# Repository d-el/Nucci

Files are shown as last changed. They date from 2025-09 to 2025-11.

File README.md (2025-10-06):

# Nucci -- NUClear Counter Interface

## Overview

- IPS 160x128 pixel front panel display
- 10/100BASE-T Ethernet
- Modbus TCP for remote programming
- Web interface for monitoring

## Specifications and features

Current consumption from a 3.7V battery is 0.142A (3.408Ah per twenty-four hours) with the backlight on, 0.114A (2.736Ah per twenty-four hours) with the backlight off.

The detector tube voltage is set from the menu in the range of 100-450V.

## Hardware

Assembly:  
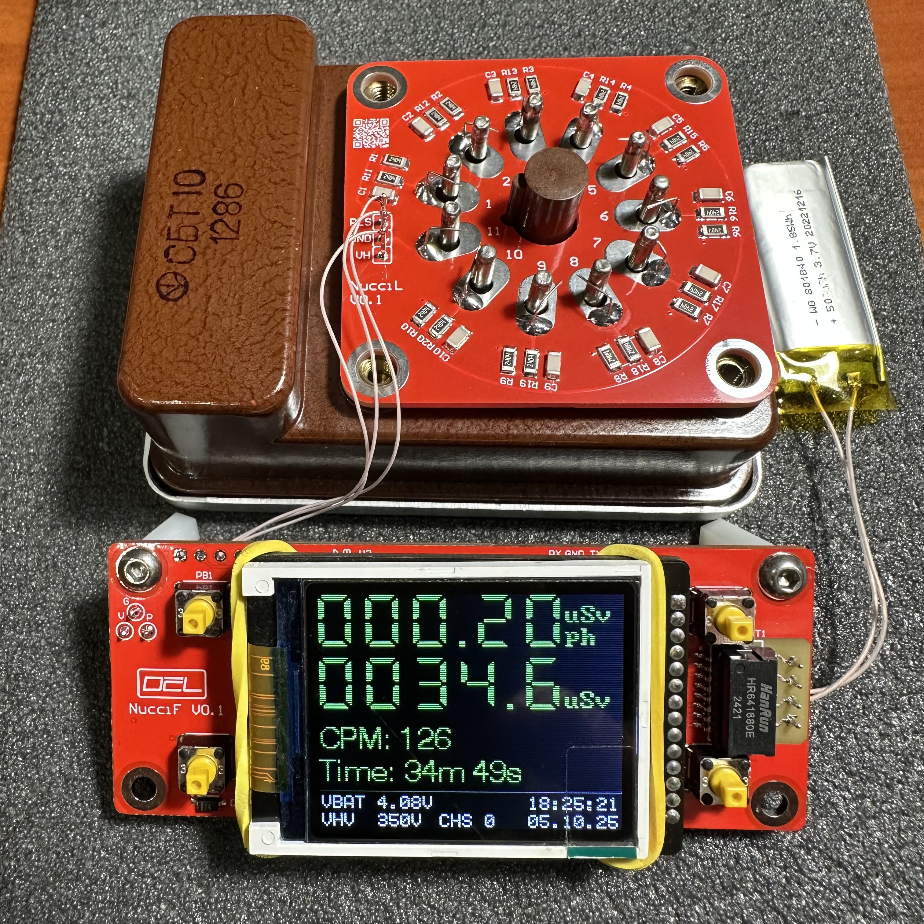
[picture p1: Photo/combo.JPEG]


PCB top:  
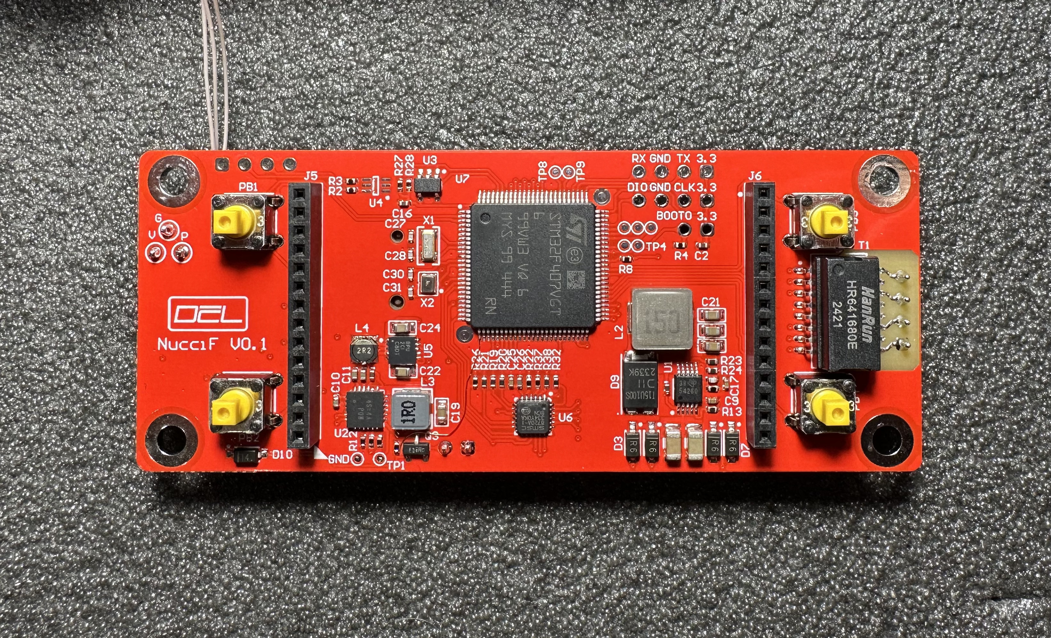
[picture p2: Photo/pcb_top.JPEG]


PCB bottom:  
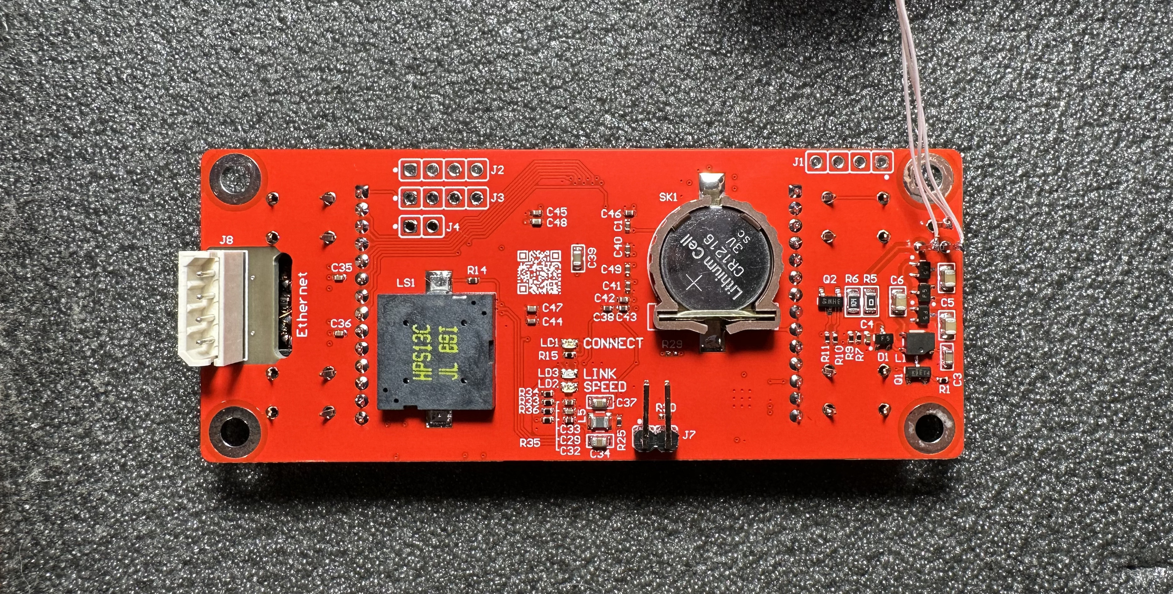
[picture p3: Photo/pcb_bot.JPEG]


SBT10 connector:  
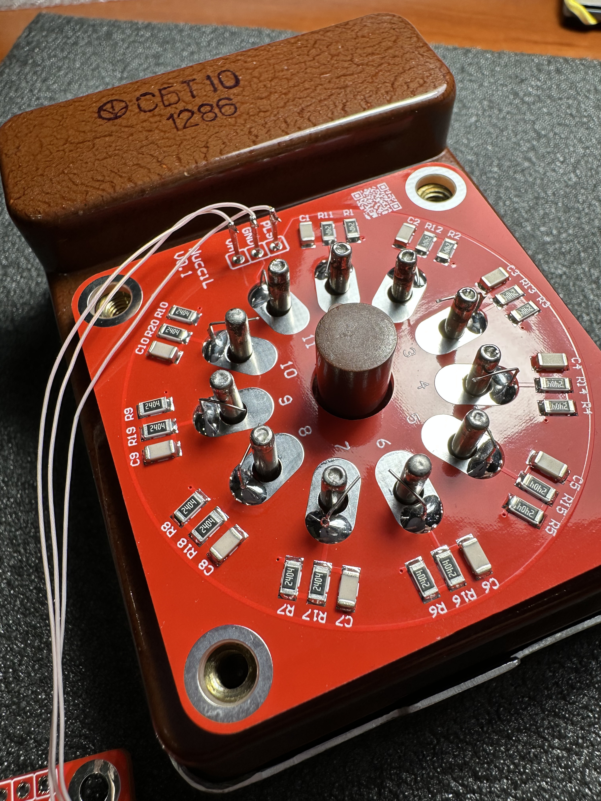
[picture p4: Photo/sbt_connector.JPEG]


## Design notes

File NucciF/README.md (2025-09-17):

# Nucci

### Overview
This repository include the source code of the counter on Geiger tube.  
MCU: STM32F407VG.

### Requirements
toolchain arm-none-eabi 14.2.1 or higher  
gcc / g++ 13.3.0 or higher  
cmake 3.14 or higher  
libjsoncpp-dev  

### Build project
>mkdir build  
>cd build  
>cmake .. -G "Unix Makefiles" -DCMAKE_TOOLCHAIN_FILE=../toolchain.cmake -DCMAKE_BUILD_TYPE=Release  
>make -j8  

#### Start debug server
>./scripts/gdb-serv.sh openocd-jlink

#### Start debug client
>./scripts/gdb-client.sh

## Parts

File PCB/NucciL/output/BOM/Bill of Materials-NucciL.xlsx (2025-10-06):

Designator | Comment | Footprint | Part Number | Part Description | Quantity
C1, C2, C3, C4, C5, C6, C7, C8, C9, C10 | 10p | CAPC3216X70N | CC1206_10PF_500V_5%_NP0 | SMD Multilayer Chip Ceramic Capacitor | 10
R1, R2, R3, R4, R5, R6, R7, R8, R9, R10, R11, R12, R13, R14, R15, R16, R17, R18, R19, R20 | 2M4 | RESC3216X65N | R1206_2M4_1%_0.25W_100PPM | General Purpose Thick Film Chip Resistor | 20
W1 | Test Point | COMATEL_385.0358.1.03.400 | COMATEL_385.0358.1.03.400 | 3 Contacts Straight Strip Header Pitch 2.54mm L=6.3mm ''Mini-Wire-Wrap'' | 1

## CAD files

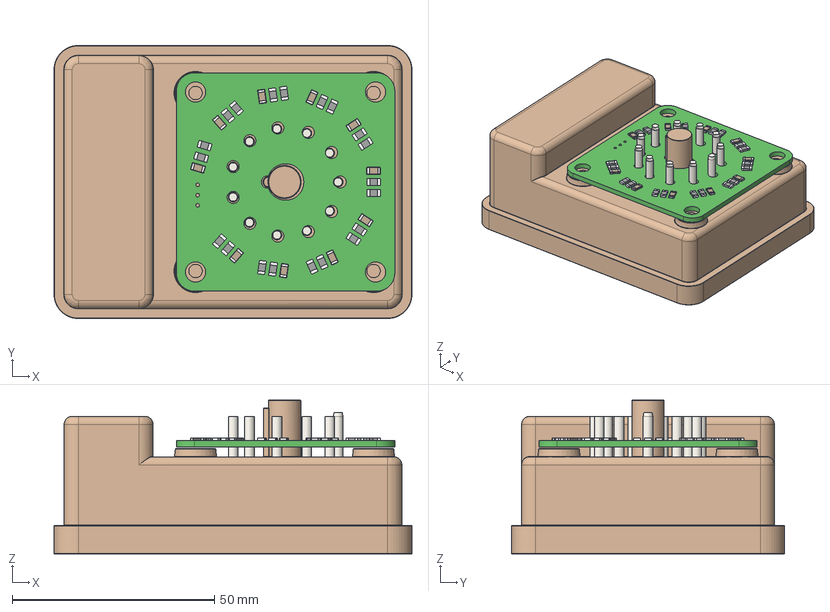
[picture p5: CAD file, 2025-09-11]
PCB/NucciL/NucciL.step
88.5 x 67.5 x 38.0 mm
RESC3216X65N x 20
CAPC3216X70N x 10
SBT-10A_Sonde

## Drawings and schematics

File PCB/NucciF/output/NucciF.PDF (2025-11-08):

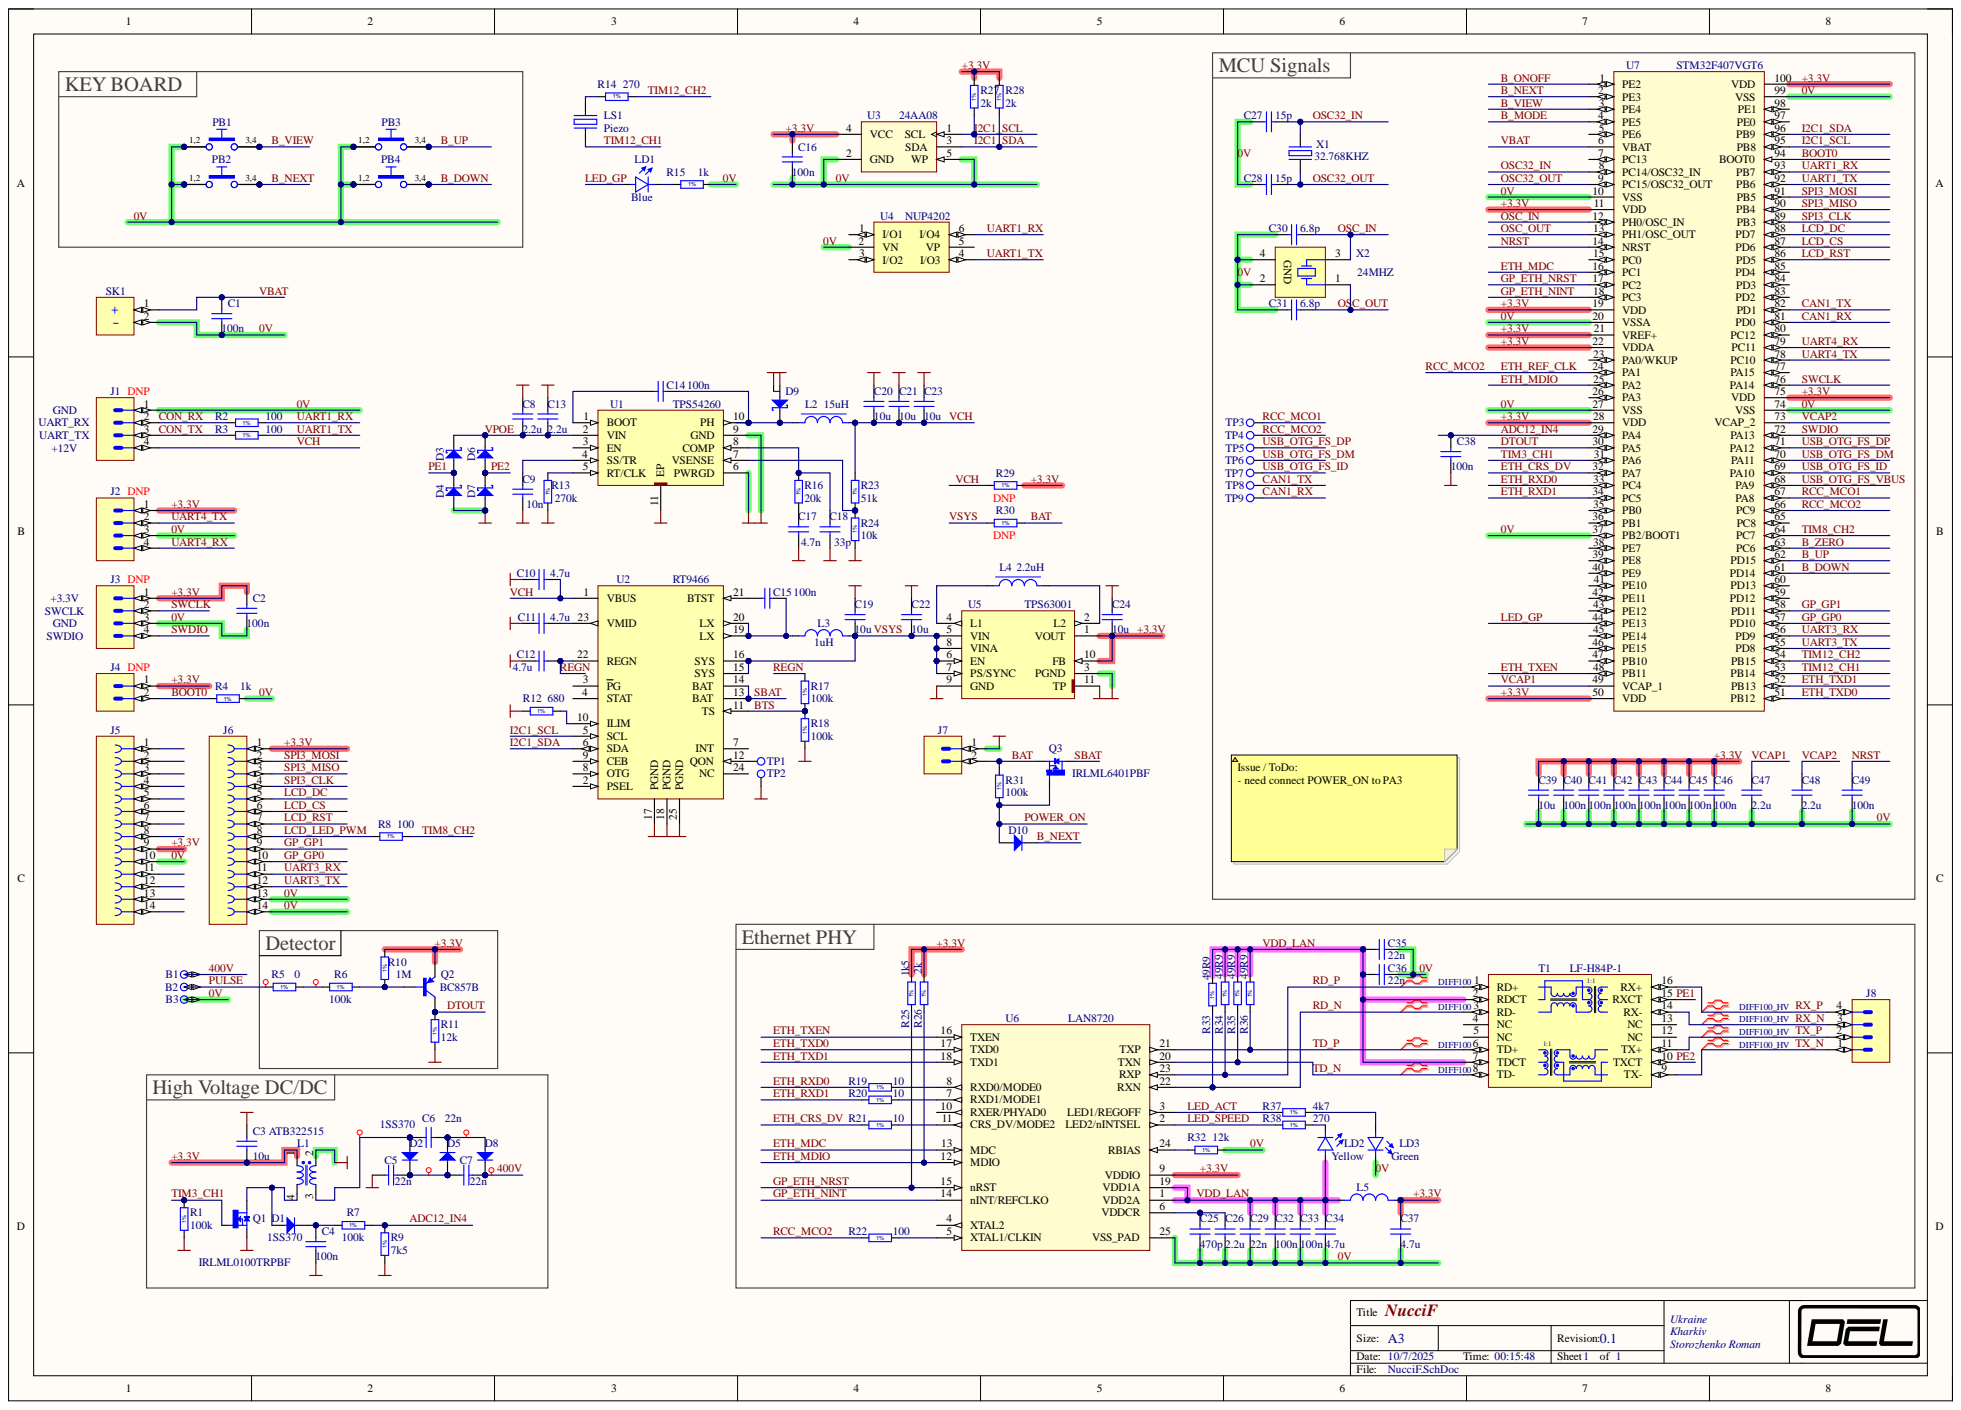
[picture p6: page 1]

High Voltage DC/DC

Designator | Comment | Footprint | Part Number | Part Description | Quant ity
B1, B2, B3 | V, P, G | c150h100 | PLATED_HOLE1.0_PAD1.5 | Plated Through Hole: Hole Dia.=1.0mm Pad Dia.=1.5mm | 3
C1, C2, C4, C16, C32, C33, C38, C40, C41, C42, C43, C44, C45, C46, C49 | 100n | CAPC1005X55N | CC0402_100NF_50V_10%_X7R | SMD Multilayer Chip Ceramic Capacitor | 15
C3, C19, C20, C21, C22, C23, C24, C39 | 10u | CAPC1608X87N | CC0603_10UF_10V_20%_X5R | SMD Multilayer Chip Ceramic Capacitor | 8
C5, C6, C7 | 22n | CAPC2012X135N | CC0805_22NF_500V_10%_X7R | SMD Multilayer Chip Ceramic Capacitor | 3
C8, C13 | 2.2u | CAPC3216X140N | CC1206_2.2UF_100V_10%_X7R | SMD Multilayer Chip Ceramic Capacitor | 2
C9 | 10n | CAPC1005X55N | CC0402_10NF_16V_10%_X7R | SMD Multilayer Chip Ceramic Capacitor | 1
C10, C11, C12 | 4.7u | CAPC1005X55N | CC0402_4.7UF_10V_20%_X5R | SMD Multilayer Chip Ceramic Capacitor | 3
C14, C15 | 100n | CAPC1005X55N | CC0402_100NF_16V_10%_X7R | SMD Multilayer Chip Ceramic Capacitor | 2
C17 | 4.7n | CAPC1005X55N | CC0402_4.7NF_16V_10%_X7R | SMD Multilayer Chip Ceramic Capacitor | 1
C18 | 33p | CAPC1005X55N | CC0402_33PF_50V_5%_NP0 | SMD Multilayer Chip Ceramic Capacitor | 1
C25 | 470p | CAPC1005X55N | CC0402_470PF_50V_10%_X7R | SMD Multilayer Chip Ceramic Capacitor | 1
C26, C47, C48 | 2.2u | CAPC1005X55N | CC0402_2.2UF_6.3V_20%_X5R | SMD Multilayer Chip Ceramic Capacitor | 3
C27, C28 | 15p | CAPC1005X55N | CC0402_15PF_50V_5%_NP0 | SMD Multilayer Chip Ceramic Capacitor | 2
C29, C35, C36 | 22n | CAPC1005X55N | CC0402_22NF_16V_10%_X7R | SMD Multilayer Chip Ceramic Capacitor | 3
C30, C31 | 6.8p | CAPC1005X55N | CC0402_6.8PF_50V_0.5PF_NP0 | SMD Multilayer Chip Ceramic Capacitor | 2
C34, C37 | 4.7u | CAPC1608X87N | CC0603_4.7UF_10V_10%_X5R | SMD Multilayer Chip Ceramic Capacitor | 2
D1, D2, D5, D8 | 1SS370 | SOT65P210X100-3N | 1SS370 | High Voltage, High Speed Switching Applications | 4
D3, D4, D6, D7 | MBR0540T1G | SOD3716X135N | MBR0540T1G | Schottky Power Rectifier | 4
D9 | SBRT15U100SP5 | SBRT15U100SP5 | SBRT15U100SP5 | Schottky Rectifier | 1
D10 | 1N4148W | SOD3715X145N | 1N4148W | Small Signal Diode | 1
J1, J2, J3 | Header 4 | 3M_2304-6111-TG | 3M_2304-6111-TG | 4 Contacts - Vertival Contacts Straight Strip Header Pitch 2.54 | 3
J4, J7 | Header 2 | 3M_2302-6111-TG | 3M_2302-6111-TG | 2 Contacts - Horizontal Contacts Straight Strip Header Pitch 2.54 | 2
J5, J6 | Socket 14 | 3M_955114-6102-AR | 3M_955114-6102-AR | 14 Contacts - 2mm x 2 mm Straight, Boardmount Socket, 950 Serie | 2
J8 | SPOX | MOLEX_22-03-5045 | MOLEX_22-03-5045 | 2.50mm Pitch SPOX Wire-to-Board Header, Vertical, Shrouded, 4 Circuits, Tin (Sn) Plating | 1
L1 | ATB322515 | XFMR_ATB322515-0110-T000 | XFMR_TDK_ATB322515-0110-T000 | 1:10 Step-up Transformers | 1
L2 | 15uH | IND_VISHAY_IHLP-2525CZ | IND_15UH_20%_HPI0630 | SMT Inductors SIMID Series | 1
L3 | 1uH | IND_COILCRAFT_XAL4020 | IND_1UH_20%_COILCRAFT_XAL4020-102ME | Shielded SMD Power Inductors | 1
L4 | 2.2uH | VLS3010CX-1 | IND_2.2UH_20%_TDK_VLS3010CX-2R2M-1 | SMT Power Inductors | 1
L5 | 2.2uH | INDC2520X100N | IND1008_2.2UH_20%_TDK_MLP2520S 2R2MT0S1 | SMT Inductors | 1
LD1 | Blue | LEDC1608X80N_BLUE | LED_OF-SMD1608B | Surface Mount Red LED (0603 Case) | 1
LD2 | Yellow | LEDC1608X80N_YELLOW | LED_OF-SMD1608Y | Surface Mount Red LED (0603 Case) | 1
LD3 | Green | LEDC1608X80N_GREEN | LED_OF-SMD1608G | Surface Mount Green LED (0603 Case) | 1
LS1 | Piezo | HPS13C | HPS13C | Piezo sound generator | 1
PB1, PB2, PB3, PB4 | Push Button | PB_E-SWITCH_TL1105HF100Q | PB_E-SWITCH_TL1105HF100Q | 12VDC 50mA SPST Tactile Push-Button Switch | 4
Q1 | IRLML0100TRPBF | SOT95P237X112-3N | IRLML0100TRPBF | 100V 1.6A N-Channel HEXFET® Power MOSFET | 1
Q2 | BC857B | SOT95P230X110-3N | BC857B | 45V, 100mA PNP general-purpose transistors | 1
Q3 | IRLML6401PBF | SOT95P237X112-3N | IRLML6401PBF | -12V -4.3A P-Channel HEXFET® Power MOSFET | 1
R1, R7, R17, R18, R31 | 100k | RESC1005X40N | R0402_100K_1%_0.0625W_100PPM | General Purpose Thick Film Chip Resistor | 5
R2, R3, R8, R22 | 100 | RESC1005X40N | R0402_100R_1%_0.0625W_100PPM | General Purpose Thick Film Chip Resistor | 4
R4, R15 | 1k | RESC1005X40N | R0402_1K_1%_0.0625W_100PPM | General Purpose Thick Film Chip Resistor | 2
R5 | 0 | RESC2012X60N | R0805_0R_JUMPER | 2A (0.05R Max DC Resistance) Zero Ohm Jumper | 1
R6 | 100k | RESC2012X60N | R0805_100K_1%_0.125W_100PPM | General Purpose Thick Film Chip Resistor | 1
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

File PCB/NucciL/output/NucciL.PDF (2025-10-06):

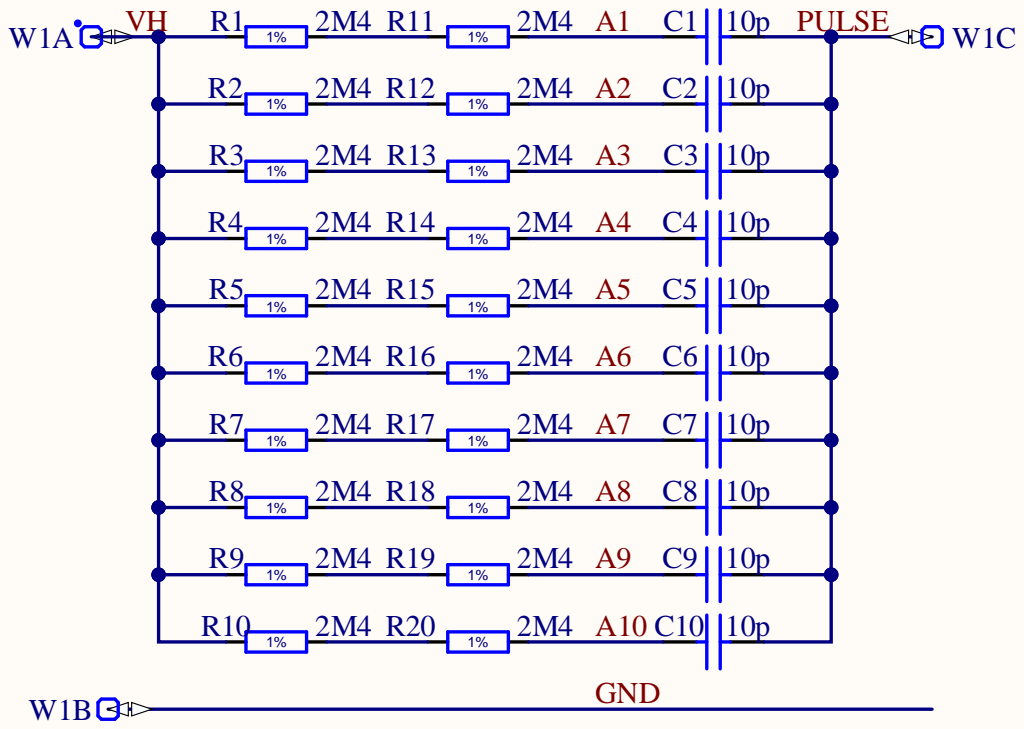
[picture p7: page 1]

Size:
D:\Radio\Devices\Nucci\PCB\NucciL\NucciL.SchDoc

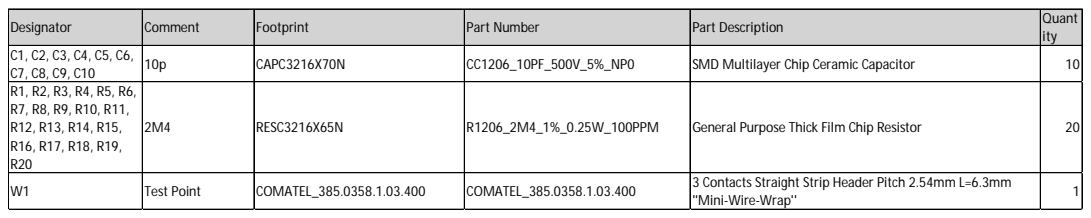
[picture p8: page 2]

Designator | Comment | Footprint | Part Number | Part Description | Quant ity

C1, C2, C3, C4, C5, C6, C7, C8, C9, C10 | 10p | CAPC3216X70N | CC1206_10PF_500V_5%_NP0 | SMD Multilayer Chip Ceramic Capacitor | 10

R1, R2, R3, R4, R5, R6, R7, R8, R9, R10, R11, R12, R13, R14, R15, R16, R17, R18, R19, R20 | 2M4 | RESC3216X65N | R1206_2M4_1%_0.25W_100PPM | General Purpose Thick Film Chip Resistor | 20

W1 | Test Point | COMATEL_385.0358.1.03.400 | COMATEL_385.0358.1.03.400 | 3 Contacts Straight Strip Header Pitch 2.54mm L=6.3mm ''Mini-Wire-Wrap'' | 1

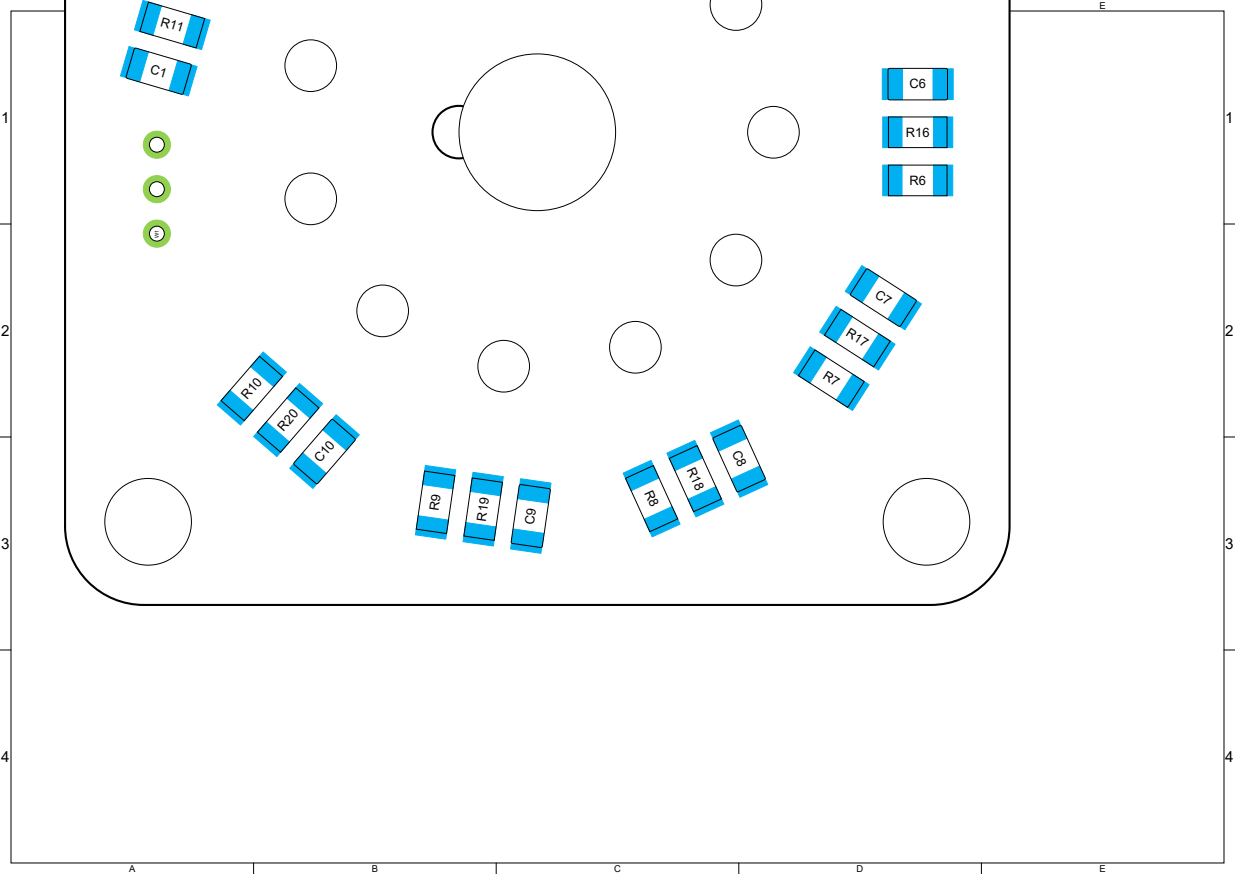
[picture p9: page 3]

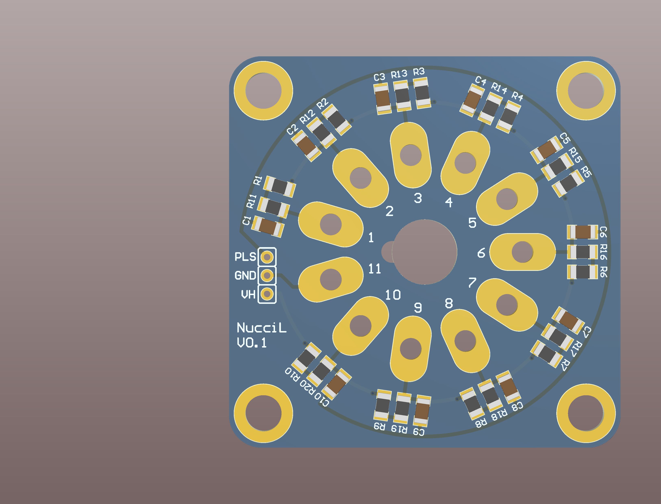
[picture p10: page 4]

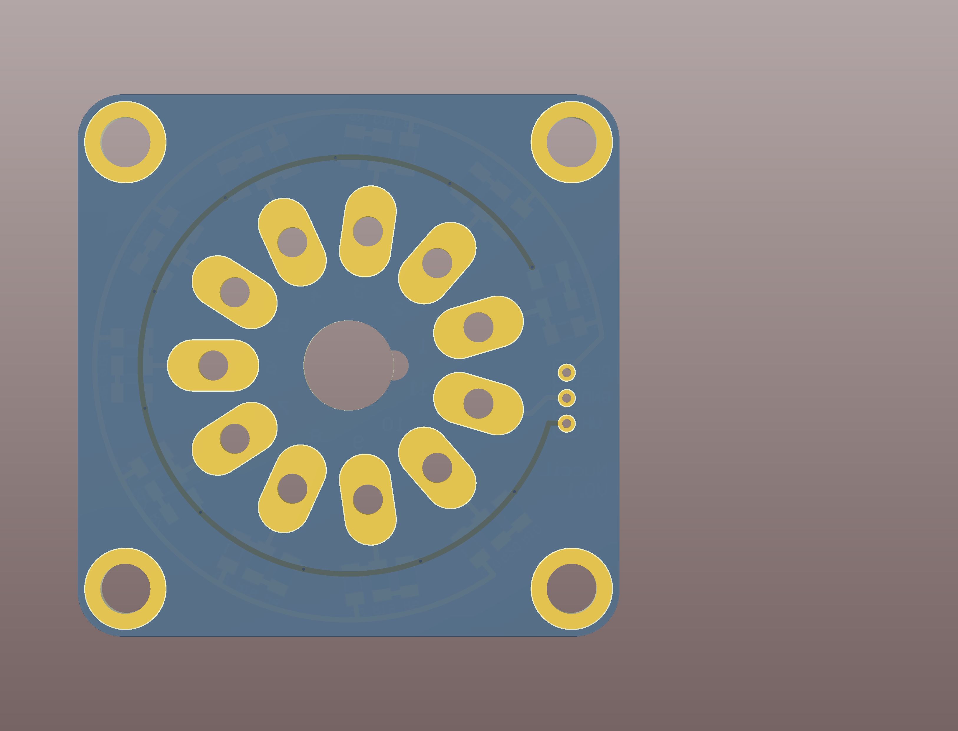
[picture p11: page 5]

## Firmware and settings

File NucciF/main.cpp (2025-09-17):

/*!******************************************************************************
 *                                                                              *
 *                                                                              *
 * @file        main.cpp                                                        *
 * @author      Storozhenko Roman - D_EL                                        *
 * @date        10.03.2025                                                      *
 * @copyright   The MIT License (MIT). Copyright (c) 2025 Storozhenko Roman     *
 * @mainpage    Main program body                                               *
 ********************************************************************************/

/*!****************************************************************************
 * Include
 */
#include <drivers.h>
#include <systemTSK.h>

/*!****************************************************************************
 *
 */
int main(void){
	hardInit();
	OSinit();
	while(1);
	return 0;
}

/******************************** END OF FILE ********************************/

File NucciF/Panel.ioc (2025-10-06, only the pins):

Mcu.UserName=STM32F407VETx
PA1.Signal=ETH_REF_CLK
PA10.Signal=USB_OTG_FS_ID
PA11.Signal=USB_OTG_FS_DM
PA12.Signal=USB_OTG_FS_DP
PA13.Signal=SYS_JTMS-SWDIO
PA14.Signal=SYS_JTCK-SWCLK
PA2.Signal=ETH_MDIO
PA4.Signal=ADCx_IN4
PA7.Signal=ETH_CRS_DV
PA8.Signal=RCC_MCO_1
PA9.Signal=USB_OTG_FS_VBUS
PB11.Signal=ETH_TX_EN
PB12.Signal=ETH_TXD0
PB13.Signal=ETH_TXD1
PB14.Signal=S_TIM12_CH1
PB15.Signal=S_TIM12_CH2
PB3.Signal=SPI3_SCK
PB4.Signal=SPI3_MISO
PB5.Signal=SPI3_MOSI
PB6.Signal=USART1_TX
PB7.Signal=USART1_RX
PB8.Signal=I2C1_SCL
PB9.Signal=I2C1_SDA
PC1.Signal=ETH_MDC
PC10.Signal=UART4_TX
PC11.Signal=UART4_RX
PC14-OSC32_IN.Signal=RCC_OSC32_IN
PC15-OSC32_OUT.Signal=RCC_OSC32_OUT
PC4.Signal=ETH_RXD0
PC5.Signal=ETH_RXD1
PC7.Signal=S_TIM8_CH2
PC9.Signal=RCC_MCO_2
PD0.Signal=CAN1_RX
PD1.Signal=CAN1_TX
PD12.Signal=S_TIM4_CH1
PD13.Signal=S_TIM4_CH2
PD8.Signal=USART3_TX
PD9.Signal=USART3_RX
PE11.Signal=S_TIM1_CH2
PE9.Signal=S_TIM1_CH1
PH0-OSC_IN.Signal=RCC_OSC_IN
PH1-OSC_OUT.Signal=RCC_OSC_OUT

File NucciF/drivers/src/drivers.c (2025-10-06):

/*!****************************************************************************
 * @file		drivers.с
 * @author		d_el
 * @version		V1.0
 * @date		05.07.2013
 * @copyright	The MIT License (MIT). Copyright (c) 2017 Storozhenko Roman
 */

/*!****************************************************************************
 * Include
 */
#include "pvd.h"
#include "stm32f4x7_eth_bsp.h"
#include "beep.h"
#include "st7735.h"
#include "uart.h"
#include "enco.h"
#include "clock.h"
#include "ledpwm.h"
#include "rtc.h"
#include "sysTimeMeas.h"
#include "gpio.h"
#include "rng.h"
#include "systemTSK.h"
#include "uniqueDeviceId.h"
#include "i2c.h"
#include "htimer.h"

/*!****************************************************************************
 * MCU peripheral initialization
 */
void hardInit(void){
	clockState_type clockState = clock_init();
	if(clockState == clockOk){
		fp.state.mainOscillatorError = 0;
	}else{
		fp.state.mainOscillatorError = 1;
	}
	htimer_init();
	gpio_init();
	sysTimeMeasEnable();
	beep_init();
	ledPwm_init();
	if(rtc_init()){
		fp.state.rtcOscillatorError = 0;
	}else{
		fp.state.rtcOscillatorError = 1;
	}
	rng_init();
	//pvd_init();
}

/******************************** END OF FILE ********************************/

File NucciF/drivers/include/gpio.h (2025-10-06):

/*!****************************************************************************
 * @file		gpio.h
 * @author		d_el
 * @version		V1.0
 * @date		22.11.2016
 * @copyright	The MIT License (MIT). Copyright (c) 2017 Storozhenko Roman
 * @brief		gpio driver for stm32F4 microcontroller
 */
#ifndef GPIO_H
#define GPIO_H

#ifdef __cplusplus
extern "C" {
#endif

/*!****************************************************************************
 * Include
 */
#include <stdint.h>
#include "stm32f4xx.h"

/*!****************************************************************************
* User define
*/
//MODERy
#define GPIO_INPUT							0x00
#define GPIO_GP_OUT							0x01
#define GPIO_AF_MODE						0x02
#define GPIO_ANALOG_MODE					0x03
//OTy
#define GPIO_PUSH_PULL						0x00
#define GPIO_OPEN_DRAIN						0x01
//PUPDRy
#define GPIO_NO_PULL_UP_DOWN				0x00
#define GPIO_PULL_UP						0x01
#define GPIO_PULL_DOWN						0x02
#define GPIO_RESERVED						0x03
//EXT_I
#define EXTI_MODE_DISABLE					0x00
#define EXTI_MODE_RISE						0x01
#define EXTI_MODE_FALL						0x02
#define EXTI_MODE_BOTH						0x03

/*!****************************************************************************
* User typedef
*/
typedef enum{
	pinm0	= 1 << 0,
	pinm1	= 1 << 1,
	pinm2	= 1 << 2,
	pinm3	= 1 << 3,
	pinm4	= 1 << 4,
	pinm5	= 1 << 5,
	pinm6	= 1 << 6,
	pinm7	= 1 << 7,
	pinm8	= 1 << 8,
	pinm9	= 1 << 9,
	pinm10	= 1 << 10,
	pinm11	= 1 << 11,
	pinm12	= 1 << 12,
	pinm13	= 1 << 13,
	pinm14	= 1 << 14,
	pinm15	= 1 << 15,
}gpioPin_type;

typedef enum{
	analogMode,							///< 0
	digitalInput,						///< 1
	outPushPull,						///< 2
	outOpenDrain,						///< 3
	alternateFunctionPushPull,			///< 4
	alternateFunctionOpenDrain			///< 5
}gpioMode_type;

typedef enum{
	speed2MHz,
	speed10MHz,
	speed50MHz,
}gpioSpeed_type;

typedef enum{
	pullDisable,
	pullUp,
	pullDown,
}gpioPull_type;

typedef struct{
	GPIO_TypeDef	*p;					///< PORT
	uint16_t		mask;				///< MASK PIN
	uint8_t			npin;				///< NUMBER PIN
	gpioMode_type	mode		:3;		///< MODE
	uint8_t			iniState	:1;		///< Initial state
	gpioPull_type	pull		:2;		///< 0 - disable, 1 - pullUp, 2 - pullDown
	uint8_t			nAF			:4;		///< Number alternate function
}pinMode_type;

typedef enum{
///*0 */GP_bMode,
///*1 */GP_bOnOff,
/*2 */GP_bView,
/*3 */GP_bNext,
/*4 */GP_bZero,
/*5 */GP_bUp,
/*6 */GP_bDown,

/*7 */GP_LCD_RST,
/*8 */GP_LCD_CS,
/*9 */GP_LCD_DC,
/*10*/GP_GP0,
/*11*/GP_GP1,

/*12*/GP_LED_GP,

/*13*/GP_LANnINT,

/*14*/GP_MCO1,
/*15*/GP_MCO2,
/*16*/GP_IN_CNT,
/*17*/GP_POWER_ON,

GP_NOT_USED
}GPnum_type;

typedef void (*gppin_callback_t)(void);

/*!****************************************************************************
 * Macro functions
 */
#define makepin(port, npin, mode, pull, iniState, nAF)	  { port, (1<<npin), npin, mode, iniState, pull, nAF }

#define _gppin_set(port, pinmask)		port->BSRR = (uint16_t)(pinmask)
#define _gppin_reset(port, pinmask)		*((volatile uint16_t*)&(port)->BSRR + 1) =  (uint16_t)(pinmask)
#define _gppin_toggle(port, pinmask)	(port->ODR	^=(pinmask))
#define _gppin_get(port, pinmask)		(port->IDR &  (pinmask))
#define gppin_set(n)					_gppin_set(pinsMode[n].p, pinsMode[n].mask)
#define gppin_reset(n)					_gppin_reset(pinsMode[n].p, pinsMode[n].mask)
#define gppin_toggle(n)					_gppin_toggle(pinsMode[n].p, pinsMode[n].mask)
#define gppin_get(n)					_gppin_get(pinsMode[n].p, pinsMode[n].mask)


#define GPIO_TO_INT(GPIO)				(((uint32_t)(&(GPIO->MODER)) - GPIOA_BASE)>>10)
#define __PIN_TO_EXTI_IRQn(PIN)							(PIN == 0)? EXTI0_IRQn :\
														(PIN == 1)? EXTI1_IRQn :\
														(PIN == 2)? EXTI2_IRQn :\
														(PIN == 3)? EXTI3_IRQn :\
														(PIN == 4)? EXTI4_IRQn :\
														(PIN <= 9)? EXTI9_5_IRQn : EXTI15_10_IRQn
#define _PIN_TO_EXTI_IRQn(PIN)							__PIN_TO_EXTI_IRQn(PIN)
#define PIN_TO_EXTI_IRQn(PIN)							_PIN_TO_EXTI_IRQn(PIN)
#define __PIN_TO_EXTI_HANDLER(PIN)						EXTI##PIN##_IRQHandler
#define _PIN_TO_EXTI_HANDLER(PIN)						__PIN_TO_EXTI_HANDLER(PIN)
#define PIN_TO_EXTI_HANDLER(PIN)						_PIN_TO_EXTI_HANDLER(PIN)
#define _EXTI_INIT(GPIO, PIN, EXTI_MODE, NVIC_PRIORITY) do{\
						SYSCFG->EXTICR[PIN/4] = (SYSCFG->EXTICR[PIN/4] & ~((uint16_t)0x0F<<((PIN % 4)<<2)))|(GPIO_TO_INT(GPIO)<<((PIN % 4)<<2));\
						BIT_BAND_PER(EXTI->FTSR,1UL<<PIN)=!!(EXTI_MODE & 0x02);\
						BIT_BAND_PER(EXTI->RTSR,1UL<<PIN)=!!(EXTI_MODE & 0x01);\
						NVIC_SetPriority(PIN_TO_EXTI_IRQn(PIN),NVIC_PRIORITY);\
						(EXTI_MODE>0)? NVIC_EnableIRQ(PIN_TO_EXTI_IRQn(PIN)): NVIC_DisableIRQ(PIN_TO_EXTI_IRQn(PIN));\
						EXTI->PR = 1UL<<PIN;\
						BIT_BAND_PER(EXTI->IMR,1UL<<PIN)=!!(EXTI_MODE);\
						}while(0)
#define EXTI_INIT(GPIO, PIN, EXTI_MODE, NVIC_PRIORITY)	_EXTI_INIT(GPIO, PIN, EXTI_MODE, NVIC_PRIORITY)
//example: EXTI_INIT(GPIOA, 9, EXTI_MODE_BOTH, 15);

/*!****************************************************************************
 * External variables
 */
extern pinMode_type	  const pinsMode[];
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

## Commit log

2025-09-11 Add PCBs, HV converter model
    [NucciF.PrjPcb, NucciF.SchDoc, NucciL.PcbDoc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]
2025-09-17 Add firmware
    [parametres.txt]
2025-09-17 Update PCB
    [NucciF.PrjPcb, NucciF.SchDoc, NucciL.PcbDoc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]
2025-10-06 Update code for PCB V0.1
    [Bill of Materials-NucciL.xlsx, NucciF.SchDoc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]
2025-10-17 Set default IP 192.168.88.15 and GW 192.168.88.1
    [parametres.txt]
2025-11-08 Update menu; Fix enter to child;
    [parametres.txt]
